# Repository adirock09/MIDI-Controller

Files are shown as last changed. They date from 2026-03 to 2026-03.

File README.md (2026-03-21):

# MIDI-Controller
<br>
Screenshot (216)
<br>
I started with layout It has 40 Keys in 10 x 4 Layout.Top two layers are for High octave and bottom two for Low octave the three sliders are for Filter,Reverb,Modulation .I used Matrix so it uses less Gpios, It is based on Raspberry Pico.
PCB made in Kicad and modeling done in Fusion 360. Firmware is written in circuit python and uses Adafruit MIDI Library.

## Bill of Materials (BOM)

| Index | Component | Part Number | Source | Quantity | Unit Price (USD) | Total Price (USD) | Notes |
|---|---|---|---|---|---|---|---|
| 1 | Cherry MX Mechanical Keyswitch | MX2A-HC1B | meckeys.com | 4 (pack of 10) | 5 | 20 | |
| 2 | Keycaps Set | MX Compatible Keycaps | meckeys.com | 8 (pack of 5) | 1 | 8 | For 40 keys |
| 3 | Signal Diode | 1N4148TR | https://makerbazar.in/ | 4 (pack of 10) | 0.02 | 0.8 | |
| 4 | Raspberry Pi Pico | SC0917 | https://makerbazar.in/ | 1 | 4.5 | 4.5 | |
| 5 | Slide Potentiometer 10K | PTL60-15R0-103B2 | https://makerbazar.in/ | 3 | 1.1 | 3.3 | |
| 6 | PCB Fabrication | JLCPCB | JLCPCB | 1 | 26 |26 | |
| 7 | PCB Shipping | JLCPCB Shipping | JLCPCB | 1 | 22.51 | 22.51 | |
| 8 | M3 Screws | M3x16mm | Existing | 4 | 0 | 0 | Already have |
| 9 | M3 Heat-set Inserts | M3 Heatset | Existing | 4 | 0 | 0 | Already have |

### Total Project Cost
**$86.91**

## Schematic & PCB
<br>Screenshot (214)

<br>Screenshot (213)

<br>

## 3d Render
<br>Screenshot (215)
<br>Screenshot (216)

<br>Screenshot (217)

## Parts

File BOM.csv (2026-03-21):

Index | Component | Part Number | Source | Quantity | Unit Price (USD) | Total Price (USD) | Notes
1 | Cherry MX Mechanical Keyswitch | MX2A-HC1B | meckeys.com | 4 (pack of 10) | 5 | 20
2 | Keycaps Set | MX Compatible Keycaps | meckeys.com | 1 | 25.00 | 25.00 | For 40 keys
3 | Signal Diode | 1N4148TR | https://makerbazar.in/y | 4 | 0.015 | 0.6
4 | Raspberry Pi Pico | SC0917 | https://makerbazar.in/ | 1 | 5.00 | 5.00
5 | Slide Potentiometer 10K | PTL60-15R0-103B2 | https://makerbazar.in/ | 3 | 1.1 | 3.3
6 | PCB Fabrication | JLCPCB | JLCPCB | 1 | 26 | 26
7 | PCB Shipping | JLCPCB Shipping | JLCPCB | 1 | 22.51 | 22.51
8 | M3 Screws | M3x16mm | Existing | 4 | 0 | 0 | Already owned
9 | M3 Heat-set Inserts | M3 Heatset | Existing | 4 | 0 | 0 | Already owned
10 | Total |  |  |  |  | $86.91

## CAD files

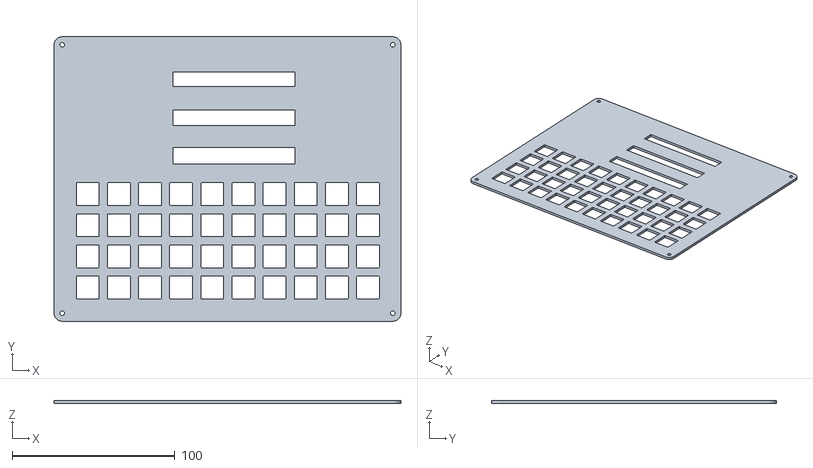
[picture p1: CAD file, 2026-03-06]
Midi Keyboard/Production/UP.stl
213.4 x 175.0 x 2.00

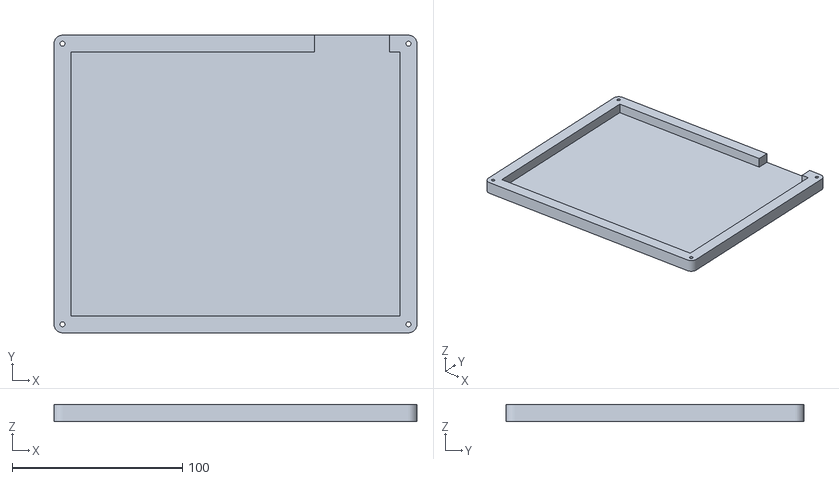
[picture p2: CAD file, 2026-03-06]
Midi Keyboard/Production/BASE.stl
213.4 x 175.0 x 10.0

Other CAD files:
Midi Keyboard/CAD/MIDI().f3d

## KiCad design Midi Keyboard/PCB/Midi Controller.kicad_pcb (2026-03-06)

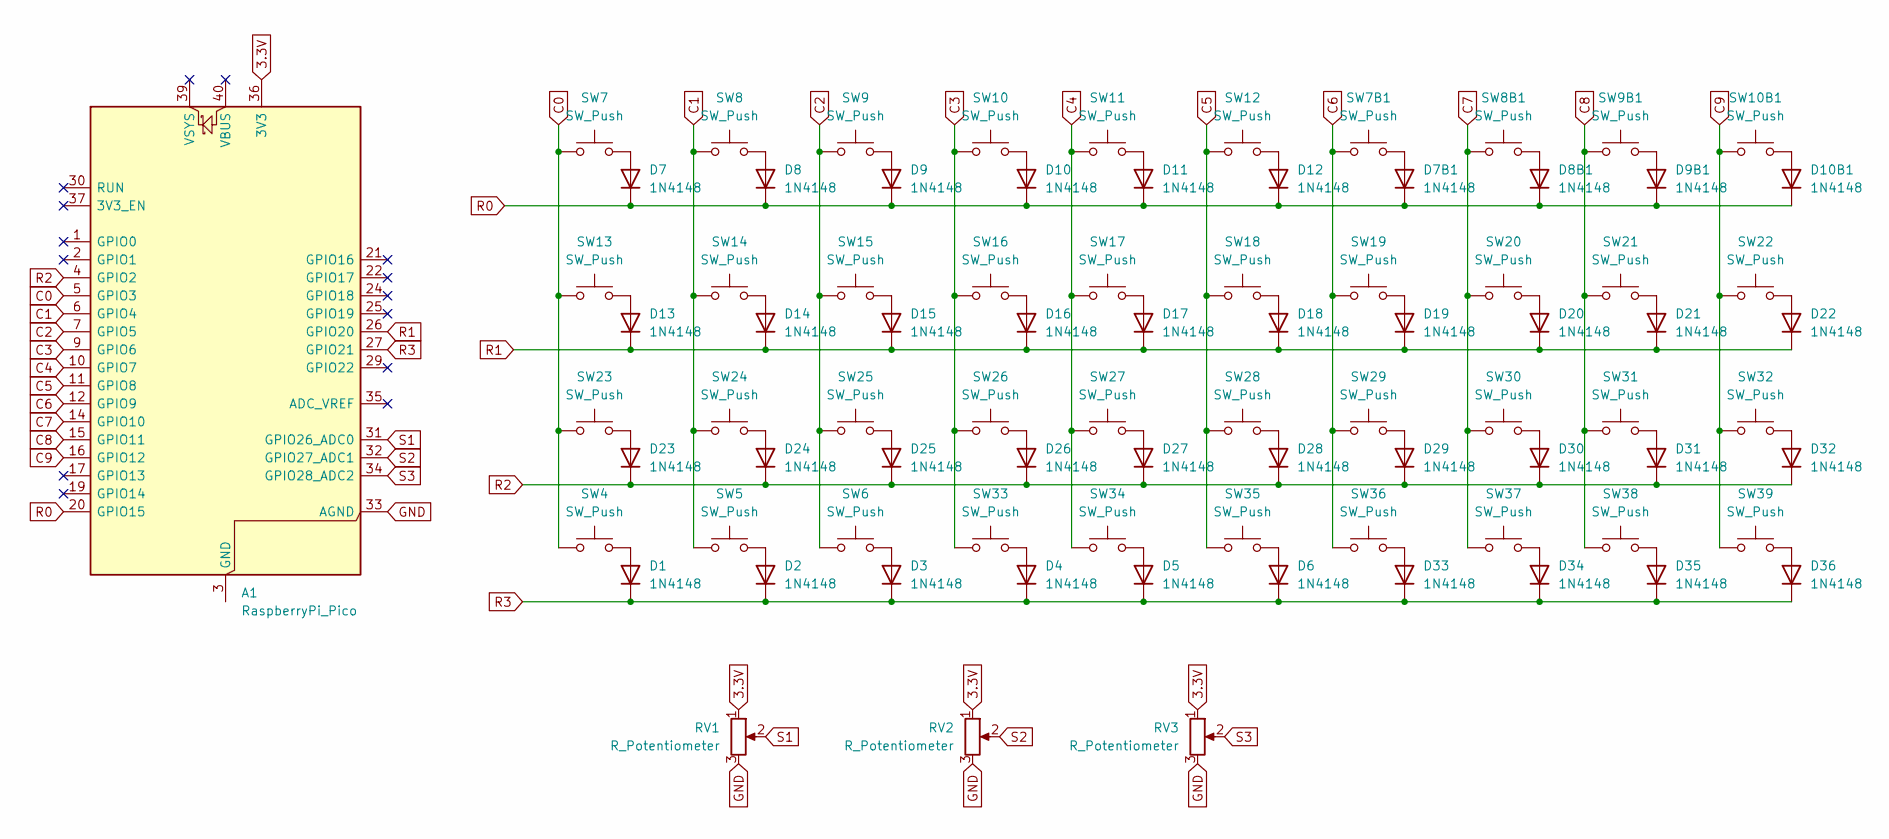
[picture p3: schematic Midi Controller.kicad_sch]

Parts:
A1: RaspberryPi_Pico; RaspberryPi_Pico_Common_Unspecified
D1, D2, D3, D4, D5, D6, D7, D7B1, D8, D8B1, D9, D9B1, D10, D10B1, D11, D12, D13, D14, D15, D16, D17, D18, D19, D20, D21, D22, D23, D24, D25, D26, D27, D28, D29, D30, D31, D32, D33, D34, D35, D36: 1N4148; D_DO-35_SOD27_P7.62mm_Horizontal
RV1, RV2, RV3: R_Potentiometer; Potentiometer_Bourns_PTA6043_Single_Slide
SW4, SW5, SW6, SW7, SW7B1, SW8, SW8B1, SW9, SW9B1, SW10, SW10B1, SW11, SW12, SW13, SW14, SW15, SW16, SW17, SW18, SW19, SW20, SW21, SW22, SW23, SW24, SW25, SW26, SW27, SW28, SW29, SW30, SW31, SW32, SW33, SW34, SW35, SW36, SW37, SW38, SW39: SW_Push; SW_Cherry_MX_1.00u_PCB

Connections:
3.3V: A1.36 (3V3), RV1.1, RV2.1, RV3.1
C0: A1.5 (GPIO3), SW4.1, SW7.1, SW13.1, SW23.1
C1: A1.6 (GPIO4), SW5.1, SW8.1, SW14.1, SW24.1
C2: A1.7 (GPIO5), SW6.1, SW9.1, SW15.1, SW25.1
C3: A1.9 (GPIO6), SW10.1, SW16.1, SW26.1, SW33.1
C4: A1.10 (GPIO7), SW11.1, SW17.1, SW27.1, SW34.1
C5: A1.11 (GPIO8), SW12.1, SW18.1, SW28.1, SW35.1
C6: A1.12 (GPIO9), SW7B1.1, SW19.1, SW29.1, SW36.1
C7: A1.14 (GPIO10), SW8B1.1, SW20.1, SW30.1, SW37.1
C8: A1.15 (GPIO11), SW9B1.1, SW21.1, SW31.1, SW38.1
C9: A1.16 (GPIO12), SW10B1.1, SW22.1, SW32.1, SW39.1
GND: A1.33 (AGND), RV1.3, RV2.3, RV3.3
unnamed: A1.3 (GND), A1.8 (GND), A1.13 (GND), A1.18 (GND), A1.23 (GND), A1.28 (GND), A1.38 (GND)
unnamed: D1.2 (A), SW4.2
unnamed: D2.2 (A), SW5.2
unnamed: D3.2 (A), SW6.2
unnamed: D4.2 (A), SW33.2
unnamed: D5.2 (A), SW34.2
unnamed: D6.2 (A), SW35.2
unnamed: D7.2 (A), SW7.2
unnamed: D7B1.2 (A), SW7B1.2
unnamed: D8.2 (A), SW8.2
unnamed: D8B1.2 (A), SW8B1.2
unnamed: D9.2 (A), SW9.2
unnamed: D9B1.2 (A), SW9B1.2
unnamed: D10.2 (A), SW10.2
unnamed: D10B1.2 (A), SW10B1.2
unnamed: D11.2 (A), SW11.2
unnamed: D12.2 (A), SW12.2
unnamed: D13.2 (A), SW13.2
unnamed: D14.2 (A), SW14.2
unnamed: D15.2 (A), SW15.2
unnamed: D16.2 (A), SW16.2
unnamed: D17.2 (A), SW17.2
unnamed: D18.2 (A), SW18.2
unnamed: D19.2 (A), SW19.2
unnamed: D20.2 (A), SW20.2
unnamed: D21.2 (A), SW21.2
unnamed: D22.2 (A), SW22.2
unnamed: D23.2 (A), SW23.2
unnamed: D24.2 (A), SW24.2
unnamed: D25.2 (A), SW25.2
unnamed: D26.2 (A), SW26.2
unnamed: D27.2 (A), SW27.2
unnamed: D28.2 (A), SW28.2
unnamed: D29.2 (A), SW29.2
unnamed: D30.2 (A), SW30.2
unnamed: D31.2 (A), SW31.2
unnamed: D32.2 (A), SW32.2
unnamed: D33.2 (A), SW36.2
unnamed: D34.2 (A), SW37.2
unnamed: D35.2 (A), SW38.2
unnamed: D36.2 (A), SW39.2
R0: A1.20 (GPIO15), D7.1 (K), D7B1.1 (K), D8.1 (K), D8B1.1 (K), D9.1 (K), D9B1.1 (K), D10.1 (K), D10B1.1 (K), D11.1 (K), D12.1 (K)
R1: A1.26 (GPIO20), D13.1 (K), D14.1 (K), D15.1 (K), D16.1 (K), D17.1 (K), D18.1 (K), D19.1 (K), D20.1 (K), D21.1 (K), D22.1 (K)
R2: A1.4 (GPIO2), D23.1 (K), D24.1 (K), D25.1 (K), D26.1 (K), D27.1 (K), D28.1 (K), D29.1 (K), D30.1 (K), D31.1 (K), D32.1 (K)
R3: A1.27 (GPIO21), D1.1 (K), D2.1 (K), D3.1 (K), D4.1 (K), D5.1 (K), D6.1 (K), D33.1 (K), D34.1 (K), D35.1 (K), D36.1 (K)
S1: A1.31 (GPIO26_ADC0), RV1.2
S2: A1.32 (GPIO27_ADC1), RV2.2
S3: A1.34 (GPIO28_ADC2), RV3.2

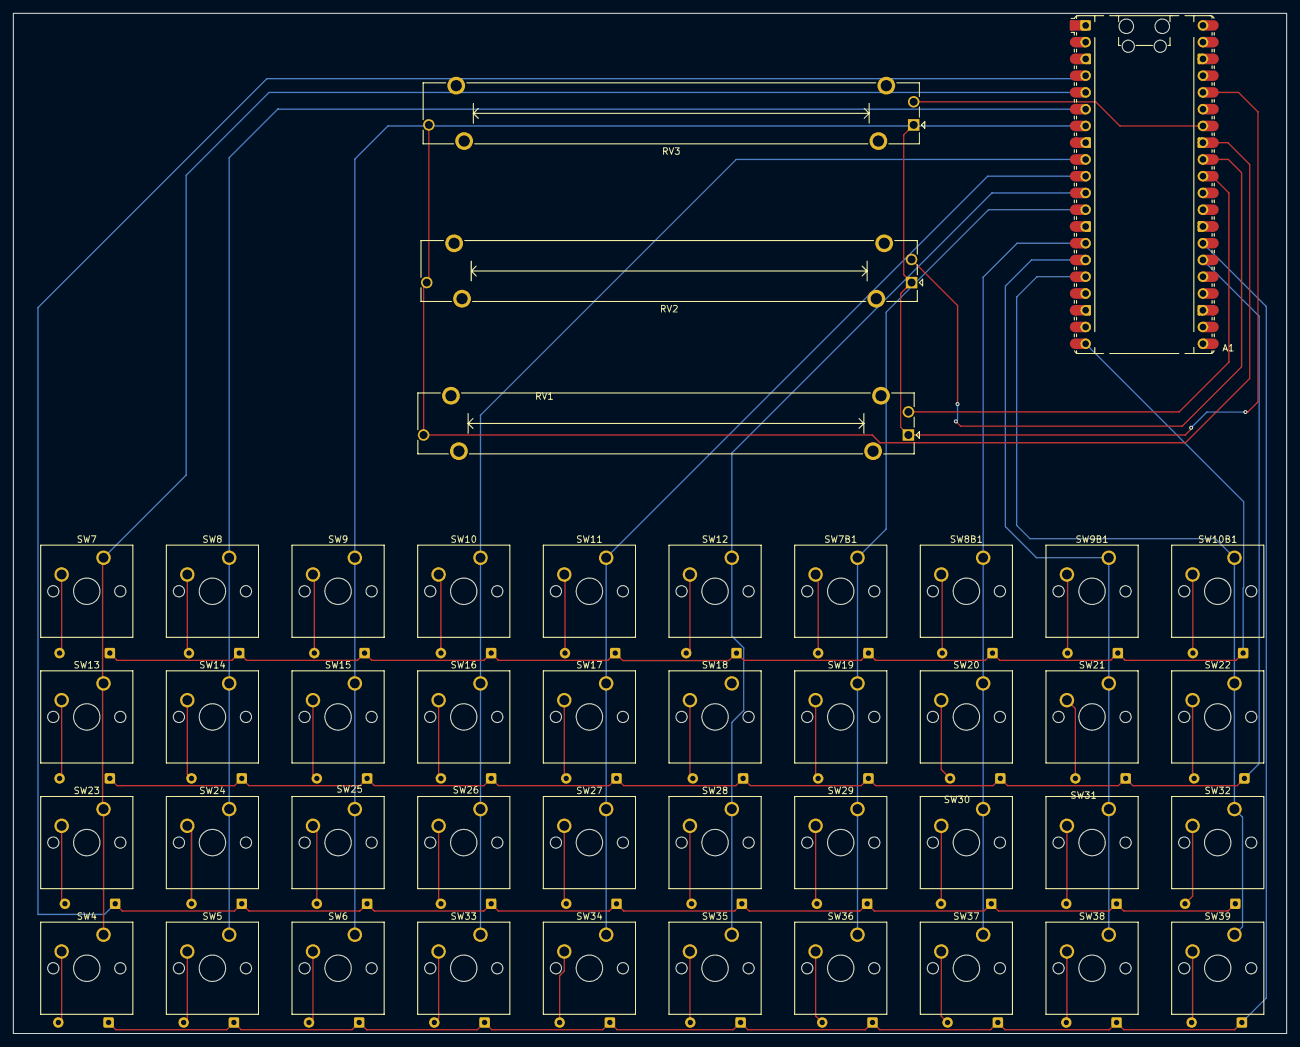
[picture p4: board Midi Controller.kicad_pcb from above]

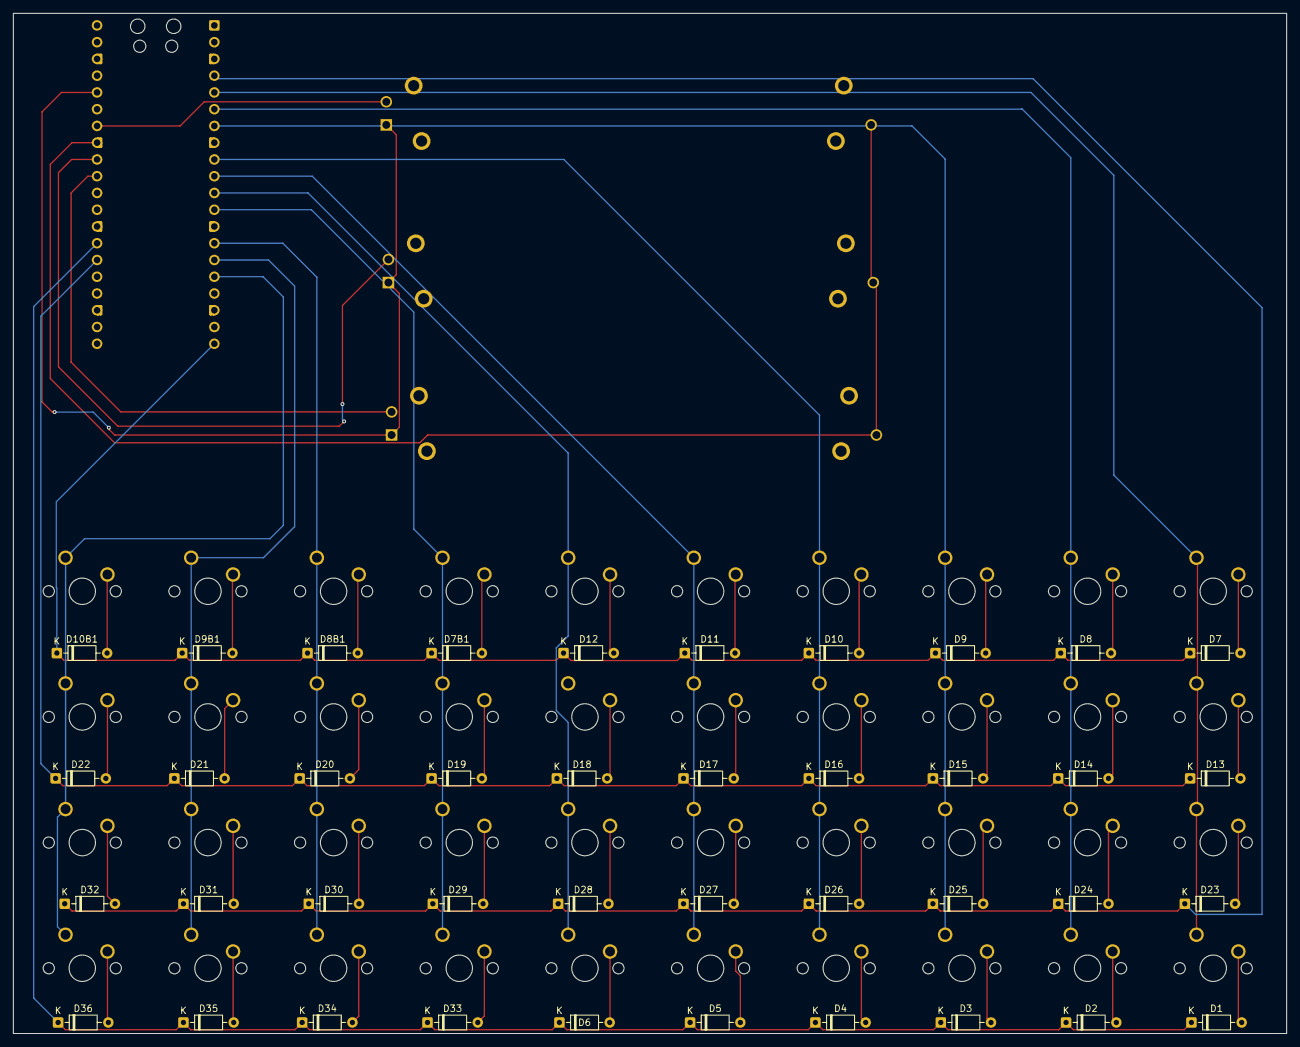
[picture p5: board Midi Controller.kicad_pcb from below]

Board: 2 copper layers, 193.0 x 154.7 mm, 84 parts (40 on the bottom side), 60 nets.

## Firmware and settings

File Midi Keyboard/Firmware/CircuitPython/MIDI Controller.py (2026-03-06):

import board
import digitalio
import analogio
import usb_midi
import time

import adafruit_midi
from adafruit_midi.note_on import NoteOn
from adafruit_midi.note_off import NoteOff
from adafruit_midi.control_change import ControlChange


# ---------------- MIDI ----------------

midi = adafruit_midi.MIDI(
    midi_out=usb_midi.ports[1],
    out_channel=0
)


# ---------------- MATRIX PINS ----------------

ROWS = [
    board.GP2,
    board.GP3,
    board.GP4,
    board.GP5
]

COLS = [
    board.GP6,
    board.GP7,
    board.GP8,
    board.GP9,
    board.GP10,
    board.GP11,
    board.GP12,
    board.GP13,
    board.GP14,
    board.GP15
]


row_pins = []
col_pins = []

for r in ROWS:
    pin = digitalio.DigitalInOut(r)
    pin.direction = digitalio.Direction.OUTPUT
    pin.value = True
    row_pins.append(pin)

for c in COLS:
    pin = digitalio.DigitalInOut(c)
    pin.direction = digitalio.Direction.INPUT
    pin.pull = digitalio.Pull.UP
    col_pins.append(pin)


pressed = [[False]*10 for _ in range(4)]


# ---------------- NOTE MAP ----------------

HIGH_NOTES = [
72,74,76,77,79,81,83,84,86,88,
89,91,93,95,96,98,100,101,103,105
]

LOW_NOTES = [
48,50,52,53,55,57,59,60,62,64,
65,67,69,71,72,74,76,77,79,81
]


# ---------------- SLIDERS ----------------

slider1 = analogio.AnalogIn(board.GP26)
slider2 = analogio.AnalogIn(board.GP27)
slider3 = analogio.AnalogIn(board.GP28)

last_slider1 = 0
last_slider2 = 0
last_slider3 = 0


# ---------------- KEY SCAN ----------------

def scan_matrix():

    for r in range(4):

        row_pins[r].value = False

        for c in range(10):

            if not col_pins[c].value:

                if not pressed[r][c]:

                    if r < 2:
                        note = HIGH_NOTES[r*10 + c]
                    else:
                        note = LOW_NOTES[(r-2)*10 + c]

                    midi.send(NoteOn(note,120))
                    pressed[r][c] = True

            else:

                if pressed[r][c]:

                    if r < 2:
                        note = HIGH_NOTES[r*10 + c]
                    else:
                        note = LOW_NOTES[(r-2)*10 + c]

                    midi.send(NoteOff(note,0))
                    pressed[r][c] = False

        row_pins[r].value = True


# ---------------- SLIDERS ----------------

def read_sliders():

    global last_slider1
    global last_slider2
    global last_slider3

    v1 = slider1.value >> 9
    v2 = slider2.value >> 9
    v3 = slider3.value >> 9

    if abs(v1 - last_slider1) > 2:
        midi.send(ControlChange(74, v1))
        last_slider1 = v1

    if abs(v2 - last_slider2) > 2:
        midi.send(ControlChange(91, v2))
        last_slider2 = v2

    if abs(v3 - last_slider3) > 2:
        midi.send(ControlChange(1, v3))
        last_slider3 = v3


# ---------------- MAIN LOOP ----------------

while True:

    scan_matrix()

    read_sliders()

    time.sleep(0.005)
